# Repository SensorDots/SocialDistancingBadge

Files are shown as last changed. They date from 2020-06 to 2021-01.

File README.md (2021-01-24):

# SensorDots Social Distancing Badge

Firmware sources for the Social Distancing Badge - https://www.kickstarter.com/projects/sensordots/the-social-distancing-badge?ref=user_menu

## Menu

Please note that menu selections are erased once power is removed from the device (i.e. if you remove the battery).

Powering on/off - When out of the menu, hold the button to turn the badge off (the display will go blank). When off, hold button to turn the badge back on. The badge will automatically turn off after a few minutes if placed into a pocket/has a constant target that is within a few centimeters.

To operate the menu, double click the button to enter the menu. Once in the menu, single click the button to rotate through the menu options. Once you are on the option you require, double click to enter that option's sub-menu. Now you can single click to change the option's value. Double click to exit the sub-menu and you can cycle through further menu options. The menu will timeout after 5 seconds.

The menu has the following hierarchy:

 - S - Speed
   - 20 - 20Hz
   - 5  - 5Hz
   - 1  - 1Hz
 
 - U - Units
   - FE - Feet
   - In - Inches
   - FI - Feet - Inches (display feet as left value and the remaining inches on the right)
   - SI - Metric Units
 
 - d - Decimal Point Location (used when in metric, when in imperial the decimal point location will change automatically)
   - mm - millimeters
   - cm - centimeters
   - m  - meters
 
 - L - Loudness
   - OF - Sound off
   - LO - Sound half volume
   - hI - Sound full volume
 
 - F - Field of View (angle)
   - 27 - 27 degrees
   - 15 - 15 degrees
   - 21 - 21 degrees
 
 - E - Effect (sound)
    - 0 - Geiger counter
    - 1 - Varying frequency clicks
    - 2 - Alien
 
 - h - Effect Threshold (distance at which the threshold will activate; value will be meters or feet depending on whether in metric or imperial modes)
  
## Hidden Debug Menu

To access the hidden debug menu:

- Double click the button to activate the menu and you will see 5 on the left of the screen.
- Hold down the button until you see "d8 7" (this means deBug Test).
- Single click to cycle through the debug menu options.

The debug settings are as follows (To activate the current menu option, double click the button when the setting is shown):

- "d8 7" - deBug Test. This will cycle through an LED, LCD and Speaker test.
- "d8 C" - deBug Calibrate. This will offset and crosstalk (if using a window cover) calibrate the sensor to a white target that is 200mm away. The LED will turn off when calibrating and turn back on when done. Click again to return to normal operation.
- "d8 d" - deBug delete calibration. This will clear any previous calibration settings.

These settings are written to the internal EEPROM on the microcontroller (unlike the main menu options which are wiped upon removing the battery).

## GPIO
There are three ATMEGA328PB GPIO pins broken out to the ABCDEF pins on the right hand side of the board. They have the following pinout:
- A - VCC (Battery Voltage - 3.1-3.6V)
- B - GND
- C - GND
- D - PD7 - Arduino Pin 7
- E - PB0 - Arduino Pin 8
- F - PB1 - Arduino Pin 9

The ICSP programming pins are also broken out to the top of the board. These can be used for programming via SPI or also as extra GPIO pins. They have the following pinout:

- 1 - PB4 - Arduino Pin 12 (MISO)
- 2 - VCC (Battery Voltage - 3.1-3.6V)
- 3 - PB5 - Arduino Pin 13 (SCK)
- 4 - PB3 - Arduino Pin 11 (MOSI)
- 5 - RST
- 6 - GND

They all have defines in the .ino file, so you can use them there:

```
#define GPIO_D 7
#define GPIO_E 8
#define GPIO_F 9
#define GPIO_1 12
#define GPIO_3 13
#define GPIO_4 11
```

## Firmware Programming

For setting up the full Arduino environment for development or firmware updates, please see https://sensordots.org/portmuxr_arduino (the instructions currently reference the Port MuxR, but they are the same for the Social Distancing Badge).

-----

To just load the latest precompiled hex file, without installing the Arduino IDE you can use [avrdude](https://www.nongnu.org/avrdude/) ( [Windows Version](http://download.savannah.gnu.org/releases/avrdude/avrdude-6.3-mingw32.zip) ) with the following command (substitute /dev/ttyUSBx with comX under Windows). You may need to replace the avrdude.conf file from here - https://github.com/SensorDots/SocialDistancingBadge/blob/master/doc/avrdude.conf

avrdude -v -p atmega328pb -c arduino -P /dev/ttyUSB0 -b 57600 -D -U flash:w:F1.03.hex:i

You should get the following output:

    avrdude: Version 6.3, compiled on Feb 17 2016 at 09:25:53
         Copyright (c) 2000-2005 Brian Dean, http://www.bdmicro.com/
         Copyright (c) 2007-2014 Joerg Wunsch

         System wide configuration file is "avrdude.conf"

         Using Port                    : com17
         Using Programmer              : arduino
         Overriding Baud Rate          : 57600
         AVR Part                      : ATmega328PB
         Chip Erase delay              : 9000 us
         PAGEL                         : PD7
         BS2                           : PC2
         RESET disposition             : dedicated
         RETRY pulse                   : SCK
         serial program mode           : yes
         parallel program mode         : yes
         Timeout                       : 200
         StabDelay                     : 100
         CmdexeDelay                   : 25
         SyncLoops                     : 32
         ByteDelay                     : 0
         PollIndex                     : 3
         PollValue                     : 0x53
         Memory Detail                 :

                                  Block Poll               Page                       Polled
           Memory Type Mode Delay Size  Indx Paged  Size   Size #Pages MinW  MaxW   ReadBack
           ----------- ---- ----- ----- ---- ------ ------ ---- ------ ----- ----- ---------
           eeprom        65    20     4    0 no       1024    4      0  3600  3600 0xff 0xff
           flash         65     6   128    0 yes     32768  128    256  4500  4500 0xff 0xff
           lfuse          0     0     0    0 no          1    0      0  4500  4500 0x00 0x00
           hfuse          0     0     0    0 no          1    0      0  4500  4500 0x00 0x00
           lock           0     0     0    0 no          1    0      0  4500  4500 0x00 0x00
           calibration    0     0     0    0 no          1    0      0     0     0 0x00 0x00
           signature      0     0     0    0 no          3    0      0     0     0 0x00 0x00
           efuse          0     0     0    0 no          1    0      0  4500  4500 0x00 0x00

         Programmer Type : Arduino
         Description     : Arduino
         Hardware Version: 3
         Firmware Version: 4.4
         Vtarget         : 0.3 V
         Varef           : 0.3 V
         Oscillator      : 28.800 kHz
         SCK period      : 3.3 us
    
    avrdude: AVR device initialized and ready to accept instructions
    
    Reading | ################################################## | 100% 0.02s
    
    avrdude: Device signature = 0x1e9516 (probably m328pb)
    avrdude: safemode: hfuse reads as 0
    avrdude: safemode: efuse reads as 0
    avrdude: reading input file "portmuxr_v1_00.hex"
    avrdude: writing flash (12480 bytes):
    
    Writing | ################################################## | 100% 4.14s
    
    avrdude: 12480 bytes of flash written
    avrdude: verifying flash memory against portmuxr_v1_00.hex:
    avrdude: load data flash data from input file portmuxr_v1_00.hex:
    avrdude: input file portmuxr_v1_00.hex contains 12480 bytes
    avrdude: reading on-chip flash data:
    
    Reading | ################################################## | 100% 3.82s
    
    avrdude: verifying ...
    avrdude: 12480 bytes of flash verified
    
    avrdude: safemode: hfuse reads as 0
    avrdude: safemode: efuse reads as 0
    avrdude: safemode: Fuses OK (E:00, H:00, L:00)
    
    avrdude done.  Thank you.

## Firmware Versions
The Social Distancing Badge can be queried for its firmware version on startup (re-insert the battery):

  - [F1.04](https://raw.githubusercontent.com/SensorDots/SocialDistancingBadge/master/releases/F1.04.hex) - Fix for Feet/Inch Display - [commit](https://github.com/SensorDots/SocialDistancingBadge/tree/dd6b8fbf8eaf43e7e10bf8af431262f737108c4c)
  - [F1.03](https://raw.githubusercontent.com/SensorDots/SocialDistancingBadge/master/releases/F1.03.hex) - Kickstarter Release Version - [commit](https://github.com/SensorDots/SocialDistancingBadge/tree/de15916056ef4eb462cb7ae99f545dcebe0092ae)

## Battery Details

The Social Distancing Badge comes with a battery holder that accepts a rechargeable 3.6V LIR2450 cell. The charge circuit actually charges this battery at 4.2V and can also charge any other 3.6V (with a 4.2V float charge voltage) lithium Polimer/Ion cell (you can remove the battery holder and solder directly to the pads, taking note the indicated polarity). To do this it uses the MCP73831T-2ACI (4.2V variant). More details on how this charge controller works can be found in the datasheet - https://ww1.microchip.com/downloads/en/DeviceDoc/MCP73831-Family-Data-Sheet-DS20001984H.pdf

The charge current is programmed to charge at 50mA.

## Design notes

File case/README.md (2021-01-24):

## Badge Case Files

The case consists of two parts along with a button that fits in the hole on the front of the case. The case is held together using 1.9-2.0mm screws along with heat pressed 4mm diameter nuts.

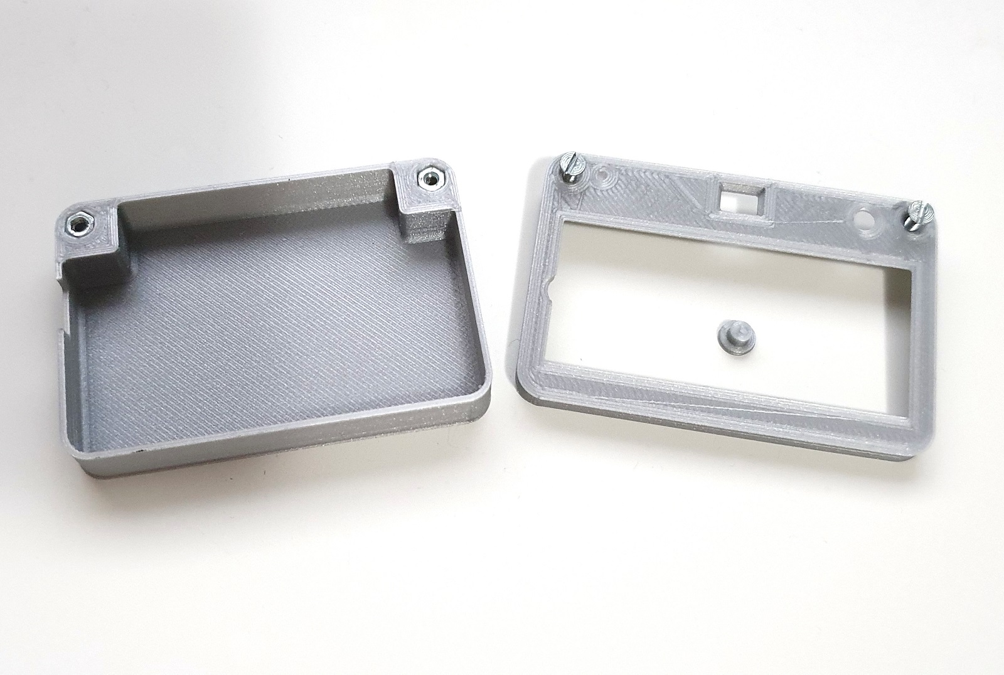
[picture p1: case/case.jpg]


It is best printed with the flat external face of the back and front directly on the bed.

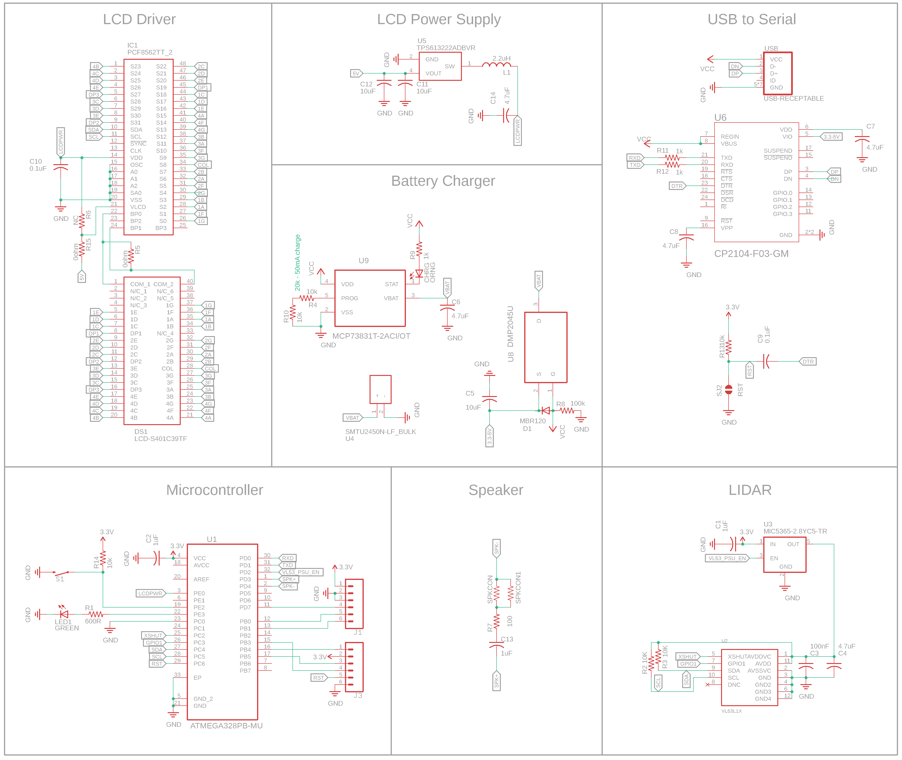
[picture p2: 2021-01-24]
schematic.png

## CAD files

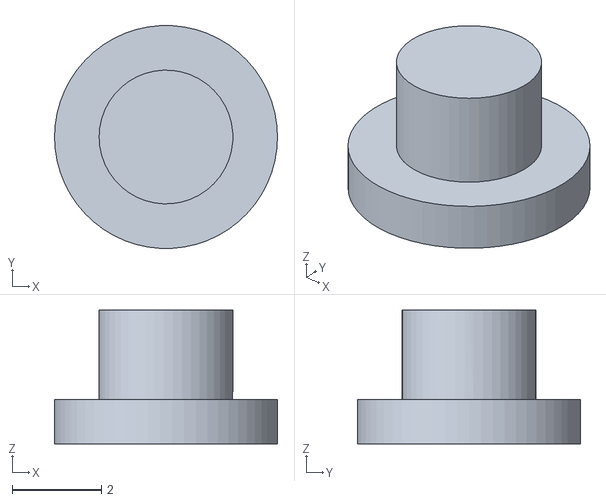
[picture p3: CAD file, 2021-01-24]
case/button.STL
5.00 x 4.99 x 3.00

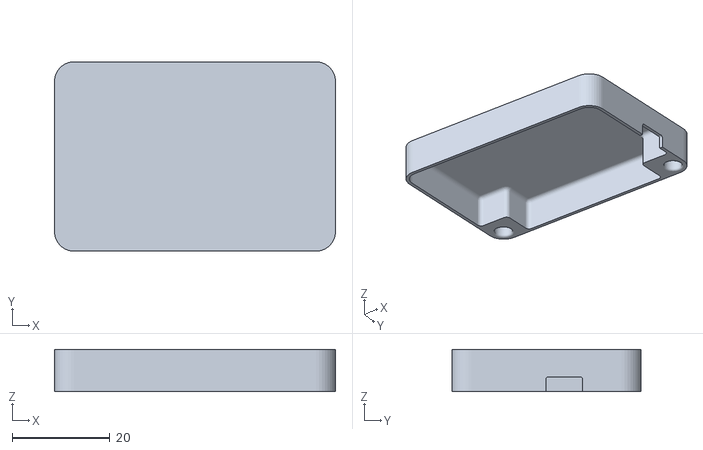
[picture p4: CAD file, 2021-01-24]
case/case-back.STL
57.5 x 38.7 x 8.60

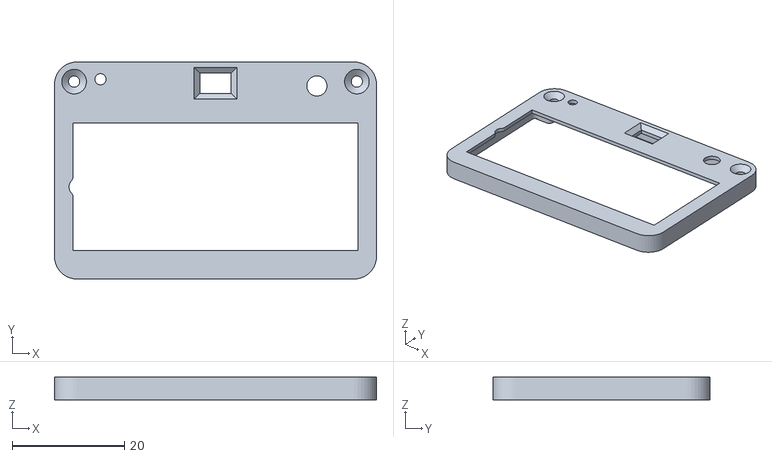
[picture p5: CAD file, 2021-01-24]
case/case-front.STL
57.5 x 38.7 x 4.10

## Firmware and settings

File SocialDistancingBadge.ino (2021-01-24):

/**
   Social Distancing Badge Firmware
   
   Copyright (C) 2020 SensorDots.org
   
   This program is free software: you can redistribute it and/or modify
   it under the terms of the GNU General Public License as published by
   the Free Software Foundation, either version 3 of the License, or
   (at your option) any later version.
   This program is distributed in the hope that it will be useful,
   but WITHOUT ANY WARRANTY; without even the implied warranty of
   MERCHANTABILITY or FITNESS FOR A PARTICULAR PURPOSE.  See the
   GNU General Public License for more details.
   You should have received a copy of the GNU General Public License
   along with this program.  If not, see <http://www.gnu.org/licenses/>.
 */

#include "ComponentObject.h"
#include "RangeSensor.h"
#include "vl53l1x_class.h"
#include "vl53l1_error_codes.h"
#include "lcd.h"
#include <avr/sleep.h>
#include <avr/power.h>
#include <avr/wdt.h>
#include <Wire.h>
#include "VL53L1X.h"
#include "OneButton.h"
#include "MenuBackend.h"
#include "bwlpf.h"
#include "history_buffer.h"
#include "ToneAC2.h"
#include <EEPROM.h>

#define VERSION 1.04

/* Averaging history size */
#define HISTORY_SIZE 10
/* Low pass filtering frequency cutoff */
#define FILTER_FREQUENCY              6  //Hz

//#define PROTOTYPE
//#define DEBUG

/* Pin Definitions */
#define SHUTDOWN_PIN   16
#define INTERRUPT_PIN  17
#define REGULATOR_2_8  2
#define LED            21
#ifdef PROTOTYPE
#define LCD_POWER      4
#else
#define LCD_POWER      22
#define SPK_NEG        4
#define SPK_POS        3
#define SPK_DC         5
#endif
#define BUTTON         20

#define GPIO_D 7
#define GPIO_E 8
#define GPIO_F 9
#define GPIO_1 12
#define GPIO_3 13
#define GPIO_4 11

#define RX 0
#define TX 1

#define PL(x) Serial.println(F(x));
#define PR(x) Serial.print(F(x));

/* Menu Definitions */
#define TWENTY_HZ 0
#define FIVE_HZ 1
#define ONE_HZ 2

#define DP_MM 0
#define DP_CM 3
#define DP_M 1

#define VOL_OFF 0
#define VOL_HIGH 2
#define VOL_LOW 1

#define FOV15 0
#define FOV21 1
#define FOV27 2

#define METRIC 0
#define FEET 1
#define INCH 2
#define FEETINCH 3

#define TOTAL_SOUND_EFFECTS 3

#define EFFECT_DELAY 10

#define GEIGER 0
#define FREQ_INCR 1
#define ALIEN 2

/* Variables */
SFEVL53L1X distanceSensor(Wire);            //VL53L1 Object

int16_t offset;                             //Offset calibration value
uint16_t crosstalk;                         //Crosstalk calibration value

volatile uint8_t volume = VOL_OFF;          //Volume setting
volatile uint8_t fov = FOV27;               //Field of view setting

OneButton button(BUTTON, true, false);      //Button object

volatile bool measurementInterrupt = false; //Measurement interrupt flag (gets triggered on VL53L1 Interrupt)

unsigned long previousButtonEventMillis;    //Previous button event time
volatile bool buttonEvent = false;          //Did button event happen?

volatile bool powerState = true;            //Current power state
volatile bool powerStateChange = false;     //Did we have a state change?

volatile uint8_t soundEffect = 0;           //Current sound effect setting

volatile uint8_t measurementMode = 0;       //Current measurement mode setting
volatile bool measurementModeChange = false;//Did we have a measurement mode change?

volatile bool interrupt_timeout_interrupt_fired = false; //Did we not get a VL53L1 interrupt after some time

volatile uint8_t decimalPointPosition = DP_MM; // Decimal point position

volatile uint8_t units = METRIC;            //Current units display setting

volatile bool runTest = false;              //Are we running tests?

volatile bool calibrating = false;          //Are we calibrating?

volatile bool clearCalib = false;           //Are we clearing calibration data?

unsigned long lastSensorReadMillis = 0;     //Last time the sensor was read

int8_t effectStartDelay = EFFECT_DELAY;     //Small delay before sound effect begins

/* Low pass filter and history buffers */
filter_state low_pass_filter_state;
uint16_t filtered_distance         = 0;
uint16_t real_distance             = 0;
uint16_t prev_real_distance        = 0;
circular_history_buffer history_buffer;
circular_history_buffer long_history_buffer;
circular_history_buffer signal_rate_history_buffer;


#ifdef DEBUG
unsigned long previousMeasurementMillis = 0; //Used for statistics during debug
#endif

bool noSignal = false;                       //Are we in a no signal state?
uint8_t noSignalCounter = 0;                 //How many no signal responses have we got?
uint8_t noSignalDisplayPosition = 0;         //Display moving decimal points to indicate no signal

bool speakerHalfVolToggle = false;           //Speaker volume

uint8_t LCDBuffer[4] = { 0 };                //LCD character display buffer

unsigned long lastSoundEffectMillis = 0;     //When did the sound effect run last for certain effects

volatile uint16_t effectThreshold = 1500;    //At which point in mm do we enabled sound effects?

void runTests();

uint16_t measurement_budget           = 50; //Current measurement budget of VL53L1 Sensor

volatile bool menuActive = false;           //Is the menu currently active?

uint16_t zeroCounter = 0;                   //How many times did we get a zero value for auto turn off

volatile bool menuDisplayChanged = false;   //Did we have a menu change event?

void menuUseEvent(MenuUseEvent used) {}

void menuChangeEvent(MenuChangeEvent changed) {}

/* Menu items instantiation */
MenuBackend menu = MenuBackend(menuUseEvent, menuChangeEvent);

/* List of menu items */
MenuItem MSpeed = MenuItem("S");    //Speed
MenuItem MSpeed20 = MenuItem("20"); //20Hz
MenuItem MSpeed5 = MenuItem("5");   //5Hz
MenuItem MSpeed1 = MenuItem("1");   //1Hz

MenuItem MFOV = MenuItem("Fo");     //Field of View
MenuItem MFOV15 = MenuItem("15");   //15 degrees
MenuItem MFOV21 = MenuItem("21");   //21 degrees
MenuItem MFOV27 = MenuItem("27");   //27 degrees

MenuItem MUnits = MenuItem("U");     //Units
MenuItem MUnitsI = MenuItem("I");    //Inches
MenuItem MUnitsM = MenuItem("M");    //Metric
MenuItem MUnitsF = MenuItem("F");    //Feet
MenuItem MUnitsFI = MenuItem("FI");  //Feet:Inches

MenuItem MVol = MenuItem("L");       //Volume
MenuItem MVolHi = MenuItem("Hi");    //High
MenuItem MVolLo = MenuItem("Lo");    //Low
MenuItem MVolOff = MenuItem("Of");   //Off

MenuItem MDP = MenuItem("d");        //Metric Decimal Point
MenuItem MDP_MM = MenuItem("mm");    //mm
MenuItem MDP_CM = MenuItem("cm");    //cm
MenuItem MDP_M = MenuItem("m");      //m

MenuItem MEffect = MenuItem("E");    //Sound Effect
MenuItem MEffect0 = MenuItem("E0");

MenuItem MThresh = MenuItem("H");    //Effect Threshold
MenuItem MThresh0 = MenuItem("H0");

MenuItem MDebug = MenuItem("DM");       //Debug Menu
MenuItem MDebugTest = MenuItem("DT");   //Test mode
MenuItem MDebugCalib = MenuItem("DC");  //Calibrate mode
MenuItem MDebugDelete = MenuItem("DD"); //Delete calibration


/* Set up the menu subsystem */
void menuSetup()
{
  menu.getRoot().add(MSpeed);

  MSpeed.addAfter(MUnits);
  MUnits.addAfter(MDP);
  MDP.addAfter(MVol);
  MVol.addAfter(MFOV);
  MFOV.addAfter(MEffect);
  MEffect.addAfter(MThresh);
  MThresh.addAfter(MSpeed);

  MDebug.addRight(MDebugTest);
  MDebugTest.addAfter(MDebugCalib);
  MDebugCalib.addAfter(MDebugDelete);
  MDebugDelete.addAfter(MDebugTest);

  MDebugTest.addLeft(MDebug);
  MDebugCalib.addLeft(MDebug);
  MDebugDelete.addLeft(MDebug);

  MSpeed.addRight(MSpeed20);
  MSpeed20.addAfter(MSpeed5);
  MSpeed5.addAfter(MSpeed1);
  MSpeed1.addAfter(MSpeed20);

  MSpeed1.addLeft(MSpeed);
  MSpeed5.addLeft(MSpeed);
  MSpeed20.addLeft(MSpeed);


  MUnits.addRight(MUnitsM);
  MUnitsM.addAfter(MUnitsF);
  MUnitsF.addAfter(MUnitsI);
  MUnitsI.addAfter(MUnitsFI);
  MUnitsFI.addAfter(MUnitsM);

  MUnitsM.addLeft(MUnits);
  MUnitsI.addLeft(MUnits);
  MUnitsF.addLeft(MUnits);
  MUnitsFI.addLeft(MUnits);

  MDP.addRight(MDP_MM);
  MDP_MM.addAfter(MDP_CM);
  MDP_CM.addAfter(MDP_M);
  MDP_M.addAfter(MDP_MM);

  MDP_MM.addLeft(MDP);
  MDP_CM.addLeft(MDP);
  MDP_M.addLeft(MDP);

  MVol.addRight(MVolLo);
  MVolLo.addAfter(MVolHi);
  MVolHi.addAfter(MVolOff);
  MVolOff.addAfter(MVolLo);

  MVolLo.addLeft(MVol);
  MVolHi.addLeft(MVol);
  MVolOff.addLeft(MVol);

  MFOV.addRight(MFOV15);
  MFOV15.addAfter(MFOV21);
  MFOV21.addAfter(MFOV27);
  MFOV27.addAfter(MFOV15);

  MFOV15.addLeft(MFOV);
  MFOV21.addLeft(MFOV);
  MFOV27.addLeft(MFOV);

  MEffect.addRight(MEffect0);
  MEffect0.addAfter(MEffect0);

  MEffect0.addLeft(MEffect);

  MThresh.addRight(MThresh0);
  MThresh0.addAfter(MThresh0);

  MThresh0.addLeft(MThresh);
}

/* Menu double click handler */
void doubleClick() {

  //Only change values if we are switched on (to prevent misclicks in sleep changing settings)
  if (menuActive && powerState) {
    
    MenuItem currentMenu = menu.getCurrent();

    if (currentMenu == MSpeed || currentMenu == MDP || currentMenu == MUnits || currentMenu == MVol || currentMenu == MFOV || currentMenu == MEffect || currentMenu == MThresh) {
      menu.moveRight(); //Move to next by default

      //Set menu to current setting if configured
      if (currentMenu == MSpeed)
      {
        if (measurementMode == TWENTY_HZ) menu.setCurrent(&MSpeed20);
        if (measurementMode == FIVE_HZ) menu.setCurrent(&MSpeed5);
        if (measurementMode == ONE_HZ) menu.setCurrent(&MSpeed1);
      }
      else if (currentMenu == MDP)
      {
        if (decimalPointPosition == DP_CM) menu.setCurrent(&MDP_CM);
        if (decimalPointPosition == DP_MM) menu.setCurrent(&MDP_MM);
        if (decimalPointPosition == DP_M) menu.setCurrent(&MDP_M);
      }
      else if (currentMenu == MUnits)
      {
        if (units == METRIC) menu.setCurrent(&MUnitsM);
        if (units == FEET)   menu.setCurrent(&MUnitsF);
        if (units == INCH)   menu.setCurrent(&MUnitsI);
        if (units == FEETINCH)   menu.setCurrent(&MUnitsFI);
      }
      else if (currentMenu == MVol)
      {
        if (volume == VOL_HIGH) menu.setCurrent(&MVolHi);
        if (volume == VOL_LOW) menu.setCurrent(&MVolLo);
        if (volume == VOL_OFF) menu.setCurrent(&MVolOff);
      }
      else if (currentMenu == MFOV)
      {
        if (fov == FOV15) menu.setCurrent(&MFOV15);
        if (fov == FOV21) menu.setCurrent(&MFOV21);
        if (fov == FOV27) menu.setCurrent(&MFOV27);
      }
      else if (currentMenu == MEffect)
      {
        menu.setCurrent(&MEffect0);
      }
      else if (currentMenu == MThresh)
      {
        menu.setCurrent(&MThresh0);
      }
    } else if (currentMenu == MDebugTest || currentMenu == MDebugCalib || currentMenu == MDebugDelete) {
      if (currentMenu == MDebugTest) {
        runTest = true;
      } else if (currentMenu == MDebugCalib) {
        calibrating = true;
      }
      else if (currentMenu == MDebugDelete) {
        clearCalib = true;
      }
    } else {
      menu.moveLeft();
    }

    menuDisplayChanged = true;

  }
  if (powerState && !menuActive)
  {
    menuActive = true;
    menu.toRoot();
    menu.moveDown();
    menuDisplayChanged = true;
  }
}

/* Menu single click handler */
void singleClick()
{
  if (powerState)
  {
    if (menuActive)
    {

      menu.moveDown();

      MenuItem currentMenu = menu.getCurrent();

      //if (currentMenu == MUnits && !metric) menu.moveDown(); //Skip DP placement if in imperial. (TODO fix this)

      if (currentMenu == MSpeed20) {
        measurementMode = TWENTY_HZ;
        measurementModeChange = true;
      }
      else if (currentMenu == MSpeed5) {
        measurementMode = FIVE_HZ;
        measurementModeChange = true;
      }
      else if (currentMenu == MSpeed1) {
        measurementMode = ONE_HZ;
        measurementModeChange = true;
      }
      else if (currentMenu == MFOV15) {
        fov = FOV15;
        measurementModeChange = true;
      }
      else if (currentMenu == MFOV21) {
        fov = FOV21;
        measurementModeChange = true;
      }
      else if (currentMenu == MFOV27) {
        fov = FOV27;
        measurementModeChange = true;
      }
      else if (currentMenu == MVolLo) {
        volume = VOL_LOW;
      }
      else if (currentMenu == MVolHi) {
        volume = VOL_HIGH;
      }
      else if (currentMenu == MVolOff) {
        volume = VOL_OFF;
      }
      else if (currentMenu == MDP_MM) {
        decimalPointPosition = DP_MM;
      }
      else if (currentMenu == MDP_CM) {
        decimalPointPosition = DP_CM;
      }
      else if (currentMenu == MDP_M) {
        decimalPointPosition = DP_M;
      }
      else if (currentMenu == MUnitsM) {
        units = METRIC;
      }
      else if (currentMenu == MUnitsI) {
        units = INCH;
      }
      else if (currentMenu == MUnitsF) {
        units = FEET;
      }
      else if (currentMenu == MUnitsFI) {
        units = FEETINCH;
      }
      else if (currentMenu == MEffect0) {
        soundEffect++;
        if (soundEffect > TOTAL_SOUND_EFFECTS - 1) soundEffect = 0;
      }
      else if (currentMenu == MThresh0) {
        effectThreshold = effectThreshold + 100;
        if (effectThreshold > 2000) effectThreshold = 100;
      }
    }
    menuDisplayChanged = true;
  }
}

/* Calibration routines */
void calibrate()
{
  //Turn off LED
#ifdef PROTOTYPE
  digitalWrite(LED, HIGH);
#else
  digitalWrite(LED, LOW);
#endif

  distanceSensor.calibrateOffset(200);
  distanceSensor.calibrateXTalk(200);
  offset = distanceSensor.getOffset();
  crosstalk = distanceSensor.getXTalk();

  EEPROM.update(0x00, 0xAA); //Set pattern for blank EEPROM

  EEPROM.update(0x10, offset & 0xff);
  EEPROM.update(0x11, offset >> 8 & 0xff);
  EEPROM.update(0x20, crosstalk);
  EEPROM.update(0x21, crosstalk >> 8 & 0xff);

#ifdef DEBUG
  PL("Calibrated");
  PR("Offset: ");
  Serial.println(offset);
  PR("Crosstalk: ");
  Serial.println(crosstalk);
#endif

  //Turn on LED
#ifdef PROTOTYPE
  digitalWrite(LED, LOW);
#else
  digitalWrite(LED, HIGH);
#endif

  delay(500);


  //Turn off LED
#ifdef PROTOTYPE
  digitalWrite(LED, HIGH);
#else
  digitalWrite(LED, LOW);
#endif

  calibrating = false;
}
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
void loop() {

  unsigned long currentMillis = millis();

  if (buttonEvent)
  {
    buttonEvent = false;
    previousButtonEventMillis = currentMillis;
  }

  if (interrupt_timeout_interrupt_fired)
  {
    interrupt_timeout_interrupt_fired = false;

    /* Reset pullup on interrupt pin. */
    pinMode(INTERRUPT_PIN, INPUT_PULLUP);

#ifdef DEBUG
    PL("Measurement Interrupt Not Fired!");
#endif

    /* Reset VL53L1 interrupt if we have a communication timeout */
    distanceSensor.clearInterrupt();
    measurementModeChange = true;
  }

  if (measurementInterrupt)
  {
    /* Reset VL53L1 no interrupt timer interrupt */
    TCNT4 = 0;

    distanceSensor.clearInterrupt();

    lastSensorReadMillis = currentMillis;

    if (!menuActive) {

      prev_real_distance = real_distance;

      real_distance = distanceSensor.getDistance(); //Get the result of the measurement from the sensor
      int32_t signalRate = distanceSensor.getSignalRate();
      int32_t avgSignalRate = 0;
      byte rangeStatus = distanceSensor.getRangeStatus();

      /* Check if we got a "zero" distance */
      if (real_distance <= 30)
      {
        zeroCounter++;
      } else {
        zeroCounter = 0;
      }

      /* Turn off badge if sensor displays the same false readout after 2 minutes 
	  (in case it's in a pocket or the like). */
      if (zeroCounter > (1000 / measurement_budget * 60 * 2))
      {
        powerStateChange = true;
        powerState = false;
      }
	  
	  /* Only filter on high update rates (because of the lower measurement time). */
      if (measurementMode == TWENTY_HZ) 
      {
        filtered_distance = bwlpf(real_distance, &low_pass_filter_state);
        /* Push current measurement into ring buffer for averaging */
        hb_push_back(&history_buffer, &filtered_distance);
        hb_push_back(&long_history_buffer, &filtered_distance);
        hb_push_back(&signal_rate_history_buffer, &signalRate);

        avgSignalRate = avg32((int32_t*)signal_rate_history_buffer.buffer, HISTORY_SIZE);

        if ((avgSignalRate > 5000) | (measurementMode == ONE_HZ))
        {
          filtered_distance = avg((uint16_t*)history_buffer.buffer, HISTORY_SIZE);
        } else {
          filtered_distance = avg((uint16_t*)long_history_buffer.buffer, HISTORY_SIZE * 2);
        }

        /* if we get an eroneous average reading, display "searching" on the display */
        if (avgSignalRate < 1500 && filtered_distance < 1000 && rangeStatus >= 2) 
        {
          noSignal = true;
        } else {
          noSignal = false;
        }

      } else {
        filtered_distance = real_distance;
		
		/* if we get an eroneous average reading, display "searching" on the display */
        if (signalRate < 600 && rangeStatus >= 2)
        {
          noSignal = true;
        } else {
          noSignal = false;
        }
      }

      /* Fix "negative" uint flashing issues with LCD writes */
      if (filtered_distance > 5000) filtered_distance = 5000;

      measurementInterrupt = false;
#ifdef DEBUG
      unsigned long testMillis = currentMillis;
#endif

      /*Note imperial measurements are all operated on with integer maths (rather than floats to avoid rounding errors)
      All these values are stored multiplied by 1000 and should be treated as such*/
	  
      uint32_t distanceInches = filtered_distance * 39.3701;
      uint32_t distanceFeet = distanceInches / 12;

#ifdef DEBUG
      PR("Distance(mm): ");
      Serial.print(filtered_distance);

      PR("\tDistance(ft): ");
      Serial.print((float)distanceFeet / 1000, 3);

      PR("\tInches(in): ");
      Serial.print((float)distanceInches / 1000, 3);

      PR("\tUpdate (hz): ");
      Serial.print((float)1000 / (millis() - previousMeasurementMillis), 1);

      PR("\tSignal rate: ");
      Serial.print(avgSignalRate);


      PR("\tStatus: ");

      //TODO change to short range when signal rate is really low (sensor works better with this)

      switch (rangeStatus)
      {
        case 0:
          PR("Good");
          break;
        case 1:
          PR("Sigma fail");
          break;
        case 2:
          PR("Signal fail");
          break;
        case 7:
          PR("Wrapped target fail");
          break;
        default:
          PR("Unknown: ");
          Serial.print(rangeStatus);
          break;
      }

      previousMeasurementMillis = currentMillis;

#endif

      lcdClear();
      if (noSignal)
      {

        if (measurementMode == TWENTY_HZ)
        {
          noSignalCounter = noSignalCounter + 2;

        } else if (measurementMode == FIVE_HZ)
        {
          noSignalCounter = noSignalCounter + 4;
        } else if (measurementMode == ONE_HZ)
        {
          noSignalCounter = noSignalCounter + 20;
        }

        if (noSignalCounter >= 20)
        {
          noSignalCounter = 0;
          noSignalDisplayPosition++;
        }

        if (noSignalDisplayPosition > 3) noSignalDisplayPosition = 0;
        lcdPrintDP(noSignalDisplayPosition);
		
      } else {
        if (units == METRIC) {
		  /* round to centimeters at long range */
          if (filtered_distance > 2000) 
          {
            filtered_distance = ((uint16_t)(filtered_distance / 10)) * 10;
          }
		  /* round to 10 cm at even longer range to stop jitter */
          if (filtered_distance > 3000) 
          {
            filtered_distance = ((uint16_t)(filtered_distance / 100)) * 100;
          }
          lcdPrintNumber(filtered_distance);
          lcdPrintDP(decimalPointPosition);
        } else if (units == FEET) {
          /* Note integer math here (values are stored x1000) */
		  
		  /* round to hundreths at long range */
          if (distanceFeet > 6000) 
          {
            distanceFeet = (distanceFeet / 10) * 10;
          }
		  /* round to tenths at longer range */
          if (distanceFeet > 9000) 
          {
            distanceFeet = (distanceFeet / 100) * 100;
          }
		  /* If digits don't overflow display, display all */
          if (distanceFeet < 10000) 
          {
            lcdPrintNumber(distanceFeet);
            lcdPrintDP(1);
          } else {
            lcdPrintNumber((int)(distanceFeet / 10));
            lcdPrintDP(2);
          }
        } else if ( units == INCH)
        {
          /* Note integer math here (values are stored x1000) */
		  
		  /* round to tenths at long range */
          if (distanceInches > 72000) 
          {
            distanceInches = (distanceInches / 100) * 100;
          }
		  /* round to inches at longer range */
          if (distanceInches > 108000) 
          {
            distanceInches = (distanceInches / 1000) * 1000;
          }
          if (distanceInches < 10000)
          {
            lcdPrintNumber(distanceInches);
            lcdPrintDP(1);
          } else if (distanceInches / 10 < 10000)
          {
            lcdPrintNumber((int)(distanceInches / 10));
            lcdPrintDP(2);
          }
          else if (distanceInches / 100 < 10000)
          {
            lcdPrintNumber((int)(distanceInches / 100));
            lcdPrintDP(3);
          }
        }
        else if ( units == FEETINCH)
        {
          int distanceInch = distanceFeet - (distanceFeet / 1000) * 1000;
          distanceFeet = (distanceFeet - distanceInch) / 1000;
          distanceInch = 12 * distanceInch / 1000;

          uint8_t LCDBuffer[4] = { 0 };
          LCDBuffer[0] = (int)(distanceFeet / 10) % 10;
          LCDBuffer[1] = (int)(distanceFeet) % 10;
          LCDBuffer[2] = (int)(distanceInch / 10) % 10;
          LCDBuffer[3] = (int)(distanceInch) % 10;

          lcdPrintColon();
          lcdPrint(LCDBuffer);
        }
      }
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

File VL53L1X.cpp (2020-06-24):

/*
  This is a library written for the VL53L1X I2C Distance sensor.

  Written by Andy England @ SparkFun Electronics, October 17th, 2017

  The sensor uses I2C to communicate, as well as a single (optional)
  interrupt line that is not currently supported in this driver.

  https://github.com/sparkfun/SparkFun_VL53L1X_Arduino_Library

  Do you like this library? Help support SparkFun. Buy a board!

  Development environment specifics:
  Arduino IDE 1.8.1

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
  You should have received a copy of the GNU General Public License
  along with this program.  If not, see <http://www.gnu.org/licenses/>.
*/

#include <stdlib.h>
#include "Arduino.h"
#include "VL53L1X.h"
#include "vl53l1x_class.h"

SFEVL53L1X::SFEVL53L1X(TwoWire &i2cPort, int shutdownPin, int interruptPin)
{
	_i2cPort = &i2cPort;
	_shutdownPin = shutdownPin;
	_interruptPin = interruptPin;
	_device = new VL53L1X(&i2cPort, shutdownPin, interruptPin);
}

bool SFEVL53L1X::init()
{
	return _device->VL53L1X_SensorInit();
}

bool SFEVL53L1X::begin()
{
	if (checkID() == false)
		return (VL53L1_ERROR_PLATFORM_SPECIFIC_START);

	return _device->VL53L1X_SensorInit();
}

/*Checks the ID of the device, returns true if ID is correct*/

bool SFEVL53L1X::checkID()
{
	uint16_t sensorId;
	_device->VL53L1X_GetSensorId(&sensorId);
	if (sensorId == 0xEACC)
		return true;
	return false;
}

/*Turns the sensor on if the Shutdown pin is connected*/

void SFEVL53L1X::sensorOn()
{
	if (_shutdownPin >= 0)
	{
		digitalWrite(_shutdownPin, HIGH);
	}
	delay(10);
}

/*Turns the sensor off if the Shutdown pin is connected*/

void SFEVL53L1X::sensorOff()
{
	if (_shutdownPin >= 0)
	{
		digitalWrite(_shutdownPin, LOW);
	}
	delay(10);
}

/*Gets the software version number of the current library installed.*/

VL53L1X_Version_t SFEVL53L1X::getSoftwareVersion()
{
	VL53L1X_Version_t tempVersion;
	_device->VL53L1X_GetSWVersion(&tempVersion);
	return tempVersion;
}

void SFEVL53L1X::setI2CAddress(uint8_t addr)
{
	_i2cAddress = addr;
	_device->VL53L1X_SetI2CAddress(addr);
}

int SFEVL53L1X::getI2CAddress()
{
	return _i2cAddress;
}

void SFEVL53L1X::clearInterrupt()
{
	_device->VL53L1X_ClearInterrupt();
}

void SFEVL53L1X::setInterruptPolarityHigh()
{
	_device->VL53L1X_SetInterruptPolarity(1);
}

void SFEVL53L1X::setInterruptPolarityLow()
{
	_device->VL53L1X_SetInterruptPolarity(0);
}

/**
 * This function gets the interrupt polarity\n
 * 1=active high (default), 0=active low
 */

uint8_t SFEVL53L1X::getInterruptPolarity()
{
	uint8_t tmp;
	_device->VL53L1X_GetInterruptPolarity(&tmp);
	return tmp;
}

void SFEVL53L1X::startRanging()
{
	_device->VL53L1X_StartRanging();
}

void SFEVL53L1X::stopRanging()
{
	_device->VL53L1X_StopRanging();
}

bool SFEVL53L1X::checkForDataReady()
{
	uint8_t dataReady;
	_device->VL53L1X_CheckForDataReady(&dataReady);
	return (bool)dataReady;
}

void SFEVL53L1X::setTimingBudgetInMs(uint16_t timingBudget)
{
	_device->VL53L1X_SetTimingBudgetInMs(timingBudget);
}

uint16_t SFEVL53L1X::getTimingBudgetInMs()
{
	uint16_t timingBudget;
	_device->VL53L1X_GetTimingBudgetInMs(&timingBudget);
	return timingBudget;
}

void SFEVL53L1X::setDistanceModeLong()
{
	_device->VL53L1X_SetDistanceMode(2);
}

void SFEVL53L1X::setDistanceModeShort()
{
	_device->VL53L1X_SetDistanceMode(1);
}

uint8_t SFEVL53L1X::getDistanceMode()
{
	uint16_t distanceMode;
	_device->VL53L1X_GetDistanceMode(&distanceMode);
	return distanceMode;
}

void SFEVL53L1X::setIntermeasurementPeriod(uint16_t intermeasurement)
{
	_device->VL53L1X_SetInterMeasurementInMs(intermeasurement);
}

uint16_t SFEVL53L1X::getIntermeasurementPeriod()
{
	uint16_t intermeasurement;
	_device->VL53L1X_GetInterMeasurementInMs(&intermeasurement);
	return intermeasurement;
}

bool SFEVL53L1X::checkBootState()
{
	uint8_t bootState;
	_device->VL53L1X_BootState(&bootState);
	return (bool)bootState;
}

uint16_t SFEVL53L1X::getSensorID()
{
	uint16_t id;
	_device->VL53L1X_GetSensorId(&id);
	return id;
}

uint16_t SFEVL53L1X::getDistance()
{
	uint16_t distance;
	_device->VL53L1X_GetDistance(&distance);
	return (int)distance;
}

uint16_t SFEVL53L1X::getSignalPerSpad()
{
	uint16_t temp;
	_device->VL53L1X_GetSignalPerSpad(&temp);
	return temp;
}

uint16_t SFEVL53L1X::getAmbientPerSpad()
{
	uint16_t temp;
	_device->VL53L1X_GetAmbientPerSpad(&temp);
	return temp;
}

uint16_t SFEVL53L1X::getSignalRate()
{
	uint16_t temp;
	_device->VL53L1X_GetSignalRate(&temp);
	return temp;
}

uint16_t SFEVL53L1X::getSpadNb()
{
	uint16_t temp;
	_device->VL53L1X_GetSpadNb(&temp);
	return temp;
}

uint16_t SFEVL53L1X::getAmbientRate()
{
	uint16_t temp;
	_device->VL53L1X_GetAmbientRate(&temp);
	return temp;
}

uint8_t SFEVL53L1X::getRangeStatus()
{
	uint8_t temp;
	_device->VL53L1X_GetRangeStatus(&temp);
	return temp;
}

void SFEVL53L1X::setOffset(int16_t offset)
{
	_device->VL53L1X_SetOffset(offset);
}

int16_t SFEVL53L1X::getOffset()
{
	int16_t temp;
	_device->VL53L1X_GetOffset(&temp);
	return temp;
}

void SFEVL53L1X::setXTalk(uint16_t xTalk)
{
	_device->VL53L1X_SetXtalk(xTalk);
}

uint16_t SFEVL53L1X::getXTalk()
{
	uint16_t temp;
	_device->VL53L1X_GetXtalk(&temp);
	return temp;
}

void SFEVL53L1X::setDistanceThreshold(uint16_t lowThresh, uint16_t hiThresh, uint8_t window)
{
	_device->VL53L1X_SetDistanceThreshold(lowThresh, hiThresh, window, 1);
}

uint16_t SFEVL53L1X::getDistanceThresholdWindow()
{
	uint16_t temp;
	_device->VL53L1X_GetDistanceThresholdWindow(&temp);
	return temp;
}

uint16_t SFEVL53L1X::getDistanceThresholdLow()
{
	uint16_t temp;
	_device->VL53L1X_GetDistanceThresholdLow(&temp);
	return temp;
}

uint16_t SFEVL53L1X::getDistanceThresholdHigh()
{
	uint16_t temp;
	_device->VL53L1X_GetDistanceThresholdHigh(&temp);
	return temp;
}

void SFEVL53L1X::setROI(uint8_t x, uint8_t y, uint8_t opticalCenter)
{
	_device->VL53L1X_SetROI(x, y, opticalCenter);
}

uint16_t SFEVL53L1X::getROIX()
{
	uint16_t tempX;
	uint16_t tempY;
	_device->VL53L1X_GetROI_XY(&tempX, &tempY);
	return tempX;
}

uint16_t SFEVL53L1X::getROIY()
{
	uint16_t tempX;
	uint16_t tempY;
	_device->VL53L1X_GetROI_XY(&tempX, &tempY);
	return tempY;
}

void SFEVL53L1X::setSignalThreshold(uint16_t signalThreshold)
{
	_device->VL53L1X_SetSignalThreshold(signalThreshold);
}

uint16_t SFEVL53L1X::getSignalThreshold()
{
	uint16_t temp;
	_device->VL53L1X_GetSignalThreshold(&temp);
	return temp;
}

void SFEVL53L1X::setSigmaThreshold(uint16_t sigmaThreshold)
{
	_device->VL53L1X_SetSigmaThreshold(sigmaThreshold);
}

uint16_t SFEVL53L1X::getSigmaThreshold()
{
	uint16_t temp;
	_device->VL53L1X_GetSigmaThreshold(&temp);
	return temp;
}

void SFEVL53L1X::startTemperatureUpdate()
{
	_device->VL53L1X_StartTemperatureUpdate();
}

void SFEVL53L1X::calibrateOffset(uint16_t targetDistanceInMm)
{
	int16_t offset = getOffset();
	_device->VL53L1X_CalibrateOffset(targetDistanceInMm, &offset);
}

void SFEVL53L1X::calibrateXTalk(uint16_t targetDistanceInMm)
{
	uint16_t xTalk = getXTalk();
	_device->VL53L1X_CalibrateXtalk(targetDistanceInMm, &xTalk);
};

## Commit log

2020-06-25 Add GPIO pin definitions
2020-07-07 Add badge case files
    [button.STL, case-back.STL, case-front.STL]
2020-07-08 Change version number for feet inch fix
    [SocialDistancingBadge.ino]
2020-07-08 Fix for feet-inch display
    https://github.com/SensorDots/SocialDistancingBadge/pull/1/commits/7497a9170650b67cf952690764d20282e531ae29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
2021-01-24 Added schematic.
2021-01-24 Fix schematic label.
2021-01-24 Fix schematic labels.
2021-01-24 Fixed ground labels in schematic.
